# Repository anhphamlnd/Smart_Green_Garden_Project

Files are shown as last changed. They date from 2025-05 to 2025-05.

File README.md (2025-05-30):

# Smart_Garden_Project
# 🌱 Smart Garden v2.1 (AVR)
## ĐẶT VẤN ĐỀ
### Khái quát
Trong thời đại công nghệ, việc ứng dụng các hệ thống thông minh sử dụng cảm
biến đang trở thành xu hướng phổ biến. Các cảm biến được tích hợp giúp thu thập dữ
liệu về nhiệt độ, ánh sáng, chuyển động, và nhiều thông tin khác. Từ đó, vườn rau có
thể tự động điều khiển, mang lại sự tiện nghi, an toàn và tiết kiệm năng lượng.
### Lý do chọn đề tài
Việc thiết kế hệ thống vườn thông minh sử dụng các cảm biến là một đề tài có
nhiều tiềm năng ứng dụng trong thực tế. Các lý do chính khiến đề tài này được lựa
chọn bao gồm: Nhu cầu ngày càng tăng về sự tiện lợi, an toàn và tiết kiệm năng lượng
trong quá trình sản xuất; Tiềm năng thị trường lớn cho các giải pháp nông nghiệp
thông minh sử dụng cảm biến có giá thành hợp lý và dễ ứng dụng; Phù hợp với thời
gian nghiên cứu và mục tiêu môn học đề ra.

### 👨‍💻 MCU: ATmega328P  
### 🧠 IDE: CodeVisionAVR  
### 📅 Dự án cuối kỳ — Hệ thống vườn thông minh bán tự động

---

## 📌 Tính năng chính

- 👏 **Điều khiển LED bằng 2 tiếng vỗ tay (KY-037)**
- 🚪 **Mở cổng servo khi phát hiện vật cản (FC-51)**
- 🌡️ **Đo và hiển thị nhiệt độ/độ ẩm bằng DHT11**
- 📟 **Hiển thị thông tin trên màn hình OLED SSD1306**
- 🚨 **Cảnh báo nhiệt độ cao bằng buzzer**
- ⏱️ **Hiển thị thời gian hoạt động hệ thống (uptime)**

---

## ⚙️ Phần cứng sử dụng

| Thiết bị | Mô tả |
|---|---|
| ATmega328P | Vi điều khiển chính |
| DHT11 | Cảm biến nhiệt độ và độ ẩm |
| KY-037 | Cảm biến âm thanh (vỗ tay) |
| FC-51 | Cảm biến vật cản hồng ngoại |
| Servo SG90 | Đóng/mở cổng thông minh |
| OLED SSD1306 (I2C) | Hiển thị dữ liệu |
| Buzzer | Cảnh báo nhiệt độ cao |
| LED | Phản hồi khi vỗ tay |

---

## 🧠 Mô tả chi tiết hoạt động

### 1. 👏 **Vỗ tay bật/tắt đèn**
- Khi phát hiện **2 tiếng vỗ tay liên tiếp**, hệ thống bật/tắt LED.
- Debounce chống nhiễu âm thanh được tích hợp.

### 2. 🚪 **Cảm biến vật cản mở cổng**
- FC-51 phát hiện người/động vật → điều khiển servo mở cửa trong 5 giây → tự đóng.

### 3. 🌡️ **Đo nhiệt độ và cảnh báo**
- Dữ liệu nhiệt độ/độ ẩm được đo mỗi 2 giây.
- Nếu nhiệt độ vượt ngưỡng (mặc định >38°C), buzzer phát cảnh báo chớp nháy.

### 4. 📟 **OLED hiển thị**
- Thông tin được cập nhật:
  - Nhiệt độ
  - Độ ẩm
  - Trạng thái cảnh báo
  - Uptime tính theo `giờ:phút:giây`

---

## 🧾 Sơ đồ kết nối (Pinout)

| Thiết bị | ATmega328P Pin |
|---|---|
| KY-037 | PD4 (Digital)  |
| FC-51 | PD5 (Digital)  |
| DHT11 | PD6 (Digital)  |
| Servo | PD3 (OC2B PWM) |
| OLED (SCL) | PC5 (A5) |
| OLED (SDA) | PC4 (A4) |
| Buzzer | PB0 (Digital)  |
| LED | PB1 (Digital)  |

---
## Chi tiết hoạt động của dự án
### Khi bắt đầu chương trình 
https://github.com/user-attachments/assets/0a29f42b-ba93-440f-8400-c172d5bd55a2

### Khối mở cửa
https://github.com/user-attachments/assets/b30ab63e-868c-456a-b049-d4f57b4c9ab6

### Khối bật tắt đèn khi clap 2 lần 
https://github.com/user-attachments/assets/f04b529f-8dd0-40fd-a486-890ce29304f3

### Cảnh báo khi nhiệt độ > 38 độ C
https://github.com/user-attachments/assets/04ab473f-949c-4921-8430-c594595824e2

## 💻 Cấu trúc chương trình

```c
- main()
  ├── init_all()
  ├── while(1)
       ├── check_clap_switch()
       ├── check_obstacle_sensor()
       ├── check_dht_and_update_display()
       └── update_uptime_display()

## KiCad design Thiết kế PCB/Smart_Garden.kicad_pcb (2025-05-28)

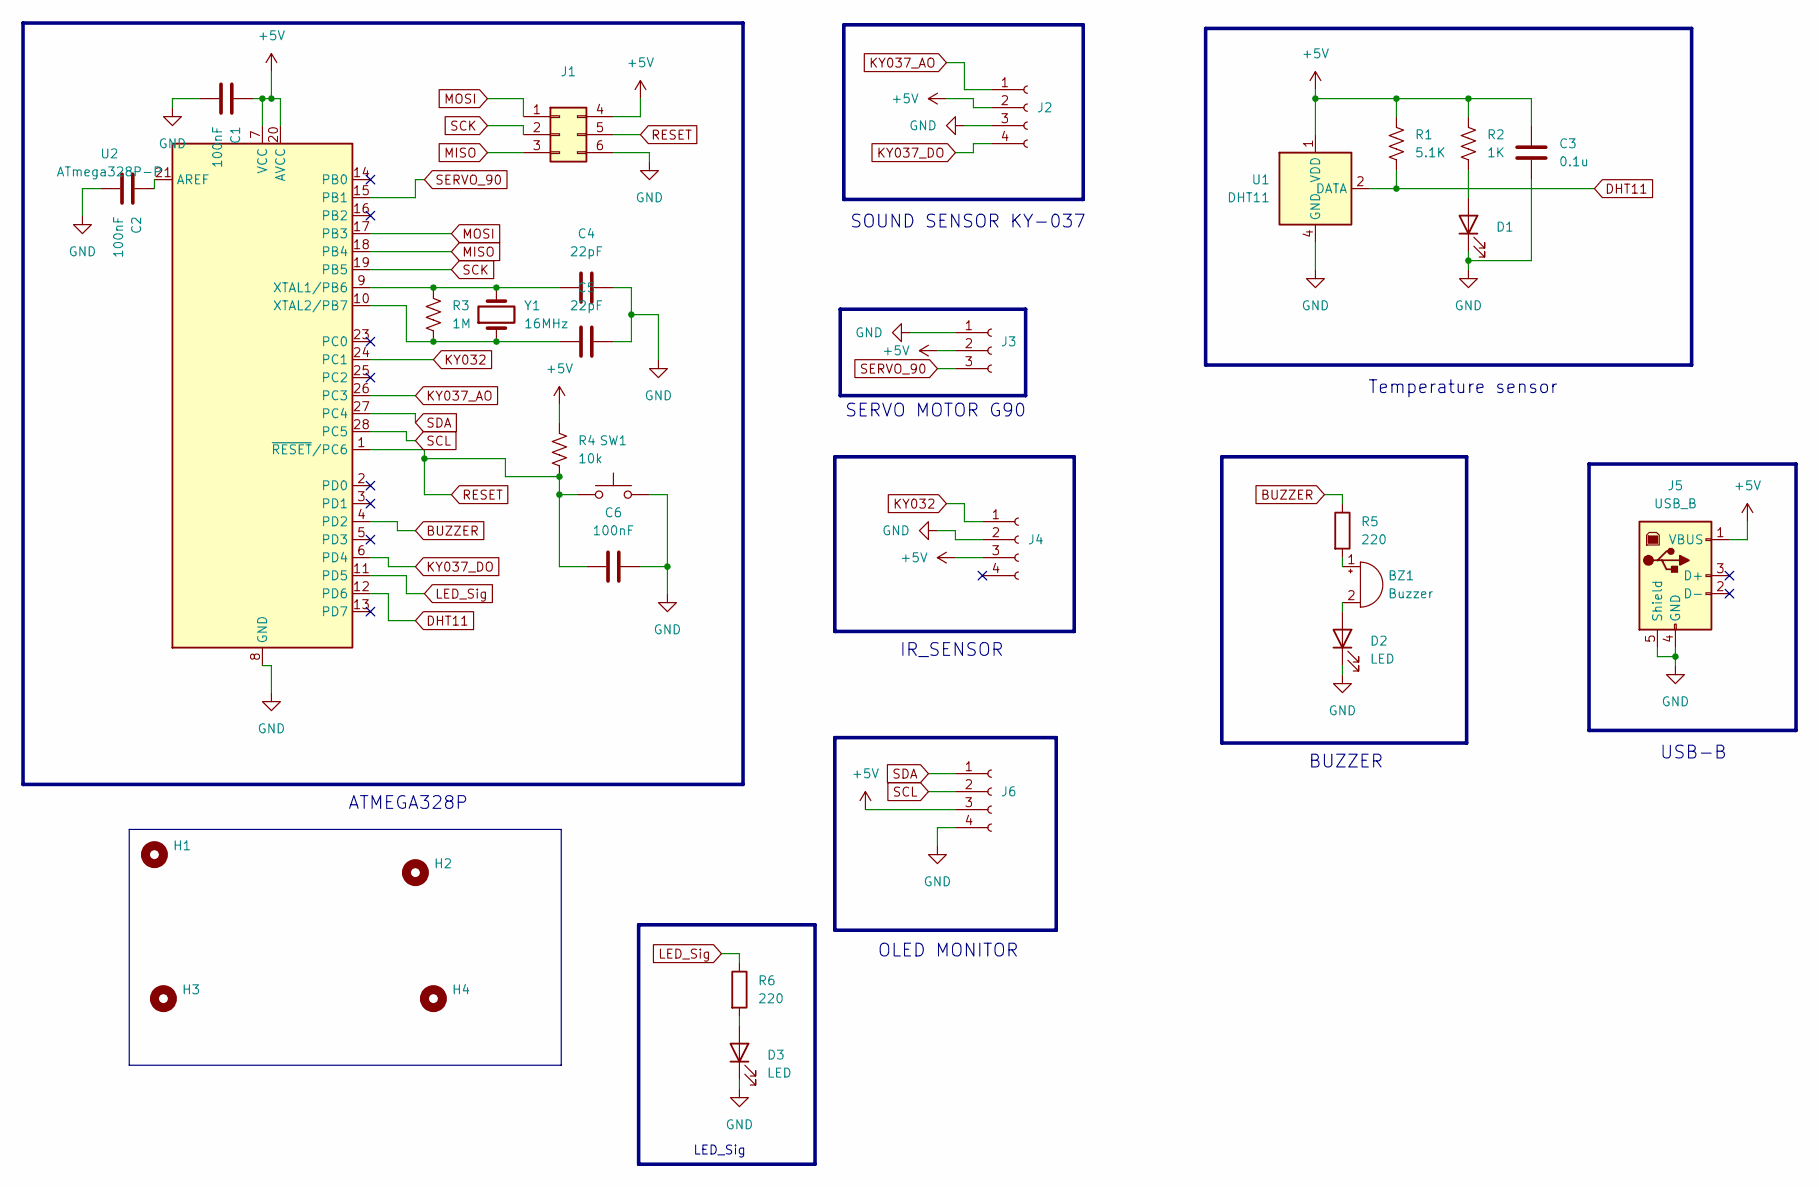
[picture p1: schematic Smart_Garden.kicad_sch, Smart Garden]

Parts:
BZ1: Buzzer; Buzzer_12x9.5RM7.6
C1, C2, C6: 100nF; CP_Radial_D4.0mm_P1.50mm
C3: 0.1u; CP_Radial_D4.0mm_P1.50mm
C4, C5: 22pF; CP_Radial_D4.0mm_P1.50mm
D1, D2, D3: LED; LED_D4.0mm
H1, H2, H3, H4: MountingHole; MountingHole_3.2mm_M3_DIN965
J1: Conn_02x03_Top_Bottom; PinSocket_2x03_P2.54mm_Vertical
J2, J4, J6: Conn_01x04_Socket; PinSocket_1x04_P2.54mm_Vertical
J3: Conn_01x03_Socket; PinSocket_1x03_P2.54mm_Vertical
J5: USB_B; USB_B_Lumberg_2411_02_Horizontal
R1: 5.1K; R_Axial_DIN0309_L9.0mm_D3.2mm_P12.70mm_Horizontal
R2: 1K; R_Axial_DIN0309_L9.0mm_D3.2mm_P12.70mm_Horizontal
R3: 1M; R_Axial_DIN0309_L9.0mm_D3.2mm_P12.70mm_Horizontal
R4: 10k; R_Axial_DIN0309_L9.0mm_D3.2mm_P12.70mm_Horizontal
R5, R6: 220; R_Axial_DIN0309_L9.0mm_D3.2mm_P12.70mm_Horizontal
SW1: SW_Push; SW_PUSH-12mm
U1: DHT11; Aosong_DHT11_5.5x12.0_P2.54mm
U2: ATmega328P-P; DIP-28_W7.62mm_Socket
Y1: 16MHz; Crystal_HC49-U_Vertical

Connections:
+5V: C1.2, C3.1, J1.4, J2.2, J3.2, J4.3, J5.1 (VBUS), J6.3, R1.1, R2.1, R4.2, U1.1 (VDD), U2.7 (VCC), U2.20 (AVCC)
BUZZER: R5.1, U2.4 (PD2)
DHT11: R1.2, U1.2 (DATA), U2.12 (PD6)
GND: C1.1, C2.1, C3.2, C4.2, C5.2, C6.2, D1.1 (K), D2.1 (K), D3.1 (K), J1.6, J2.3, J3.1, J4.2, J5.4 (GND), J5.5 (Shield), J6.4, SW1.2, U1.4 (GND), U2.8 (GND), U2.22 (GND)
KY032: J4.1, U2.24 (PC1)
KY037_AO: J2.1, U2.26 (PC3)
KY037_DO: J2.4, U2.6 (PD4)
LED_Sig: R6.1, U2.11 (PD5)
MISO: J1.3, U2.18 (PB4)
MOSI: J1.1, U2.17 (PB3)
unnamed: BZ1.1 (+), R5.2
unnamed: BZ1.2 (-), D2.2 (A)
unnamed: D1.2 (A), R2.2
unnamed: D3.2 (A), R6.2
unnamed: C2.2, U2.21 (AREF)
unnamed: C4.1, R3.1, U2.9 (XTAL1/PB6), Y1.2
unnamed: C5.1, R3.2, U2.10 (XTAL2/PB7), Y1.1
RESET: C6.1, J1.5, R4.1, SW1.1, U2.1 (~RESET/PC6)
SCK: J1.2, U2.19 (PB5)
SCL: J6.2, U2.28 (PC5)
SDA: J6.1, U2.27 (PC4)
SERVO_90: J3.3, U2.15 (PB1)

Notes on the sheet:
ATMEGA328P
OLED MONITOR
BUZZER
Temperature sensor
LED_Sig
IR_SENSOR
SOUND SENSOR KY-037
USB-B
SERVO MOTOR G90

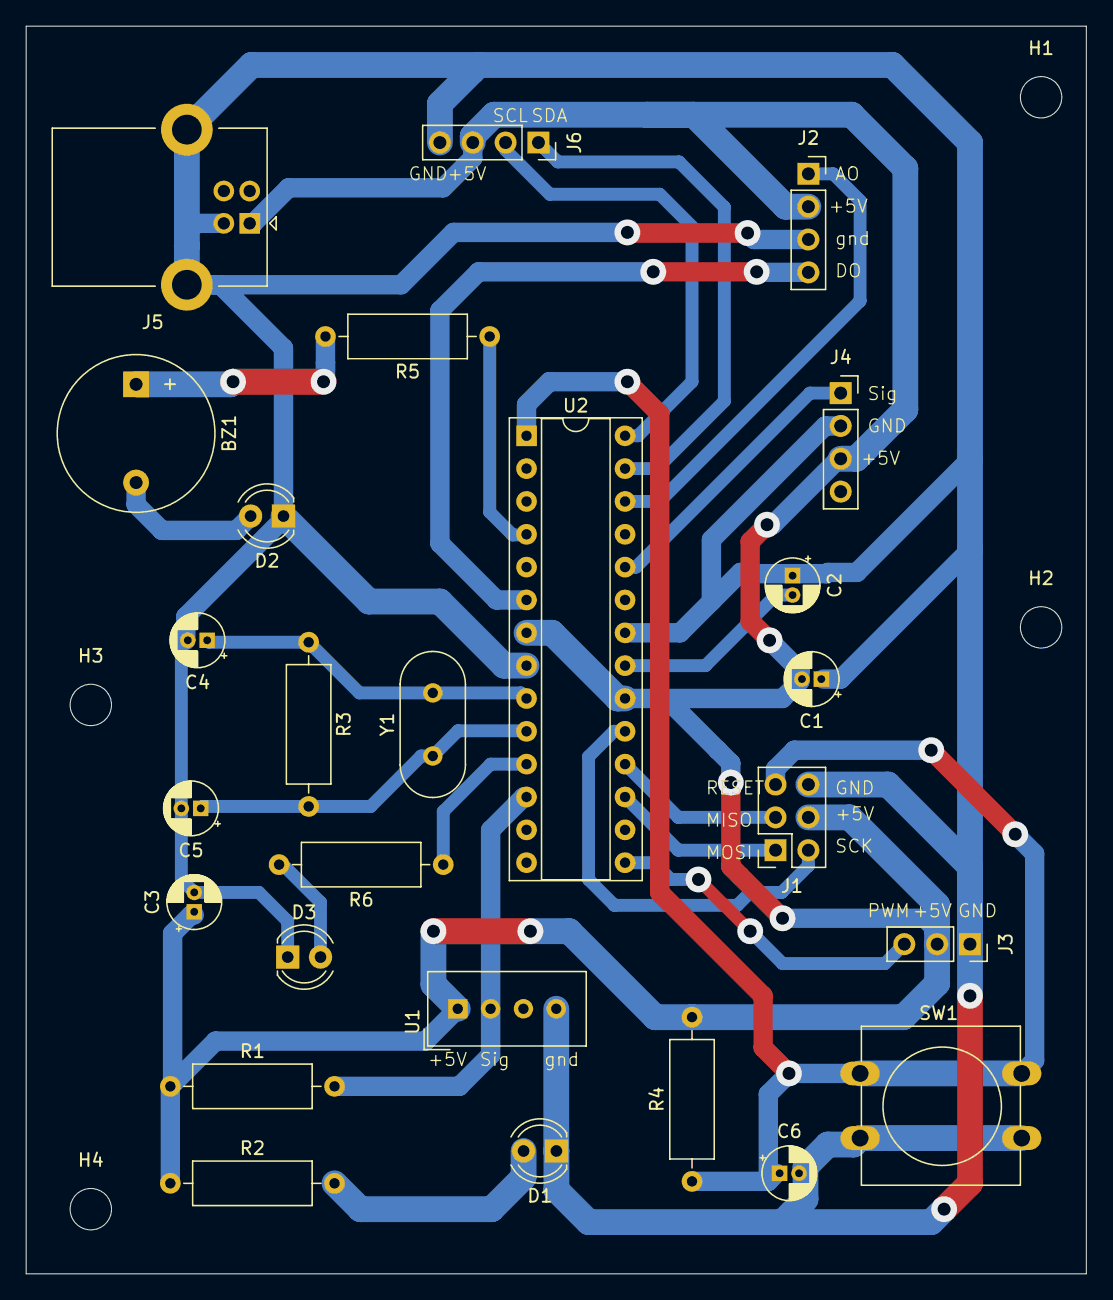
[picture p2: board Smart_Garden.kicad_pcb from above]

Board: 2 copper layers, 82.0 x 96.5 mm, 30 parts (0 on the bottom side), 22 nets.

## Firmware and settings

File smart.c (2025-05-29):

#include <mega328p.h>
#include <delay.h>
#include "oled_display.h"
#include <stdint.h>
#include <stdio.h>

// === PIN DEFINITIONS ===
// Smart Gate pins
#define DHT_PIN PIND6
#define FC51_PIN PINC1
#define BUZZER_PIN PIND2
#define SERVO_PIN PINB1

// Clap Switch pins
#define LED_PIN PIND5
#define SOUND_SENSOR_PIN PINC3

// === GLOBAL VARIABLES ===
// Timer & Millis 
volatile unsigned long millis_counter = 0;
volatile unsigned char timer_overflow_count = 0;

// DHT11 variables
unsigned int I_RH, D_RH, I_Temp, D_Temp, CheckSum;
char display_buffer[20];
unsigned char dht_error = 0;

// Gate control variables
unsigned char hasObstacle = 0, past_obstacle = 0;

// Clap switch variables 
unsigned char led_state = 0;
unsigned char sound_detected = 0;
unsigned char last_sound_state = 1; // KY-037 idle = HIGH
unsigned long clap_timer = 0;
unsigned char clap_count = 0;
unsigned char waiting_for_second_clap = 0;

// System timing
unsigned long last_dht_read = 0;
unsigned long last_display_update = 0;

// Debug variables 
unsigned int debug_seconds = 0;
unsigned long debug_last_second = 0;

// Temperature alert variables
unsigned char temp_alert_active = 0;
unsigned long temp_alert_start_time = 0;
unsigned long temp_alert_last_toggle = 0;
unsigned char temp_alert_buzzer_state = 0;

// === TIMER & MILLIS FUNCTIONS ===
void timer0_init() {
    // Clear timer registers
    TCCR0A = 0x00;
    TCCR0B = 0x00;
    TCNT0 = 0x00;
    
    // Configure for CTC mode with proper prescaler
    TCCR0A = (1 << WGM01);  // CTC mode
    TCCR0B = (1 << CS01) | (1 << CS00);  // Prescaler 64
    
    // Set compare value for 1ms interrupt at 16MHz
    // (16MHz / 64) / 1000Hz = 250
    OCR0A = 249;  // 250 - 1
    
    // Enable compare match interrupt
    TIMSK0 = (1 << OCIE0A);
    
    // Enable global interrupts
    #asm("sei");
}

// Interrupt handler
interrupt [TIM0_COMPA] void timer0_compa_isr(void) {
    millis_counter++;
    timer_overflow_count++;
    
    // Reset overflow counter every second for debug
    if (timer_overflow_count >= 1000) {  // 250 * 4ms = 1000ms
        timer_overflow_count = 0;
    }
}

unsigned long millis() {
    unsigned long temp;
    #asm("cli");
    temp = millis_counter;
    #asm("sei");
    return temp;
}

// Function to get seconds with proper handling
unsigned int get_uptime_seconds() {
    unsigned long current_millis = millis();
    return (unsigned int)(current_millis / 1000UL);
}

// Function to format uptime in human readable format
void format_uptime(char* buffer, unsigned long total_seconds) {
    unsigned int days, hours, minutes, seconds;
    
    days = total_seconds / 86400UL;     // 86400 seconds in a day
    total_seconds %= 86400UL;
    
    hours = total_seconds / 3600UL;     // 3600 seconds in an hour
    total_seconds %= 3600UL;
    
    minutes = total_seconds / 60UL;     // 60 seconds in a minute
    seconds = total_seconds % 60UL;
    
    // Format based on time duration
    if (days > 0) {
        if (hours > 0) {
            sprintf(buffer, "%ud%uh%um%us", days, hours, minutes, seconds);
        } else if (minutes > 0) {
            sprintf(buffer, "%ud%um%us", days, minutes, seconds);
        } else {
            sprintf(buffer, "%ud%us", days, seconds);
        }
    } else if (hours > 0) {
        if (minutes > 0) {
            sprintf(buffer, "%uh%um%us", hours, minutes, seconds);
        } else {
            sprintf(buffer, "%uh%us", hours, seconds);
        }
    } else if (minutes > 0) {
        sprintf(buffer, "%um%us", minutes, seconds);
    } else {
        sprintf(buffer, "%us", seconds);
    }
}

// === SERVO CONTROL FUNCTIONS ===
void servo_setup() {
    DDRB |= (1 << 1); // PB1 output (SERVO_PIN)
    
    // Timer1 setup
    TCCR1A = 0x00;
    TCCR1B = 0x00;
    TCCR1A |= (1 << WGM11);
    TCCR1B |= (1 << WGM12) | (1 << WGM13);
    TCCR1A |= (1 << COM1A1);
    TCCR1B |= (1 << CS11); // Prescaler 8
    
    // Set ICR1 = 40000 for 20ms period (exactly like your code)
    ICR1H = 0b10011100;  // 0x9C
    ICR1L = 0b01000000;  // 0x40
    
    // Initial position (closed) - using your exact values
    OCR1AH = 0b00000100;  // 0x04
    OCR1AL = 0b00100100;  // 0x24
}

void open_gate() {
    OCR1AH = 0b00001011;  // 0x0B
    OCR1AL = 0b01111100;  // 0x7C
}

void close_gate() {
    OCR1AH = 0b00000100;  // 0x04
    OCR1AL = 0b00100100;  // 0x24
}

// === DHT11 FUNCTIONS ===
void dht_request() {
    DDRD |= (1 << DHT_PIN);
    PORTD &= ~(1 << DHT_PIN);
    delay_ms(20);
    PORTD |= (1 << DHT_PIN);
    delay_us(30);
}

void dht_response() {
    DDRD &= ~(1 << DHT_PIN);
    while (PIND & (1 << DHT_PIN));
    while (!(PIND & (1 << DHT_PIN)));
    while (PIND & (1 << DHT_PIN));
}

uint8_t dht_receive_data() {
    uint8_t c = 0;
    int q;
    for (q = 0; q < 8; q++) {
        while (!(PIND & (1 << DHT_PIN)));
        delay_us(30);
        if (PIND & (1 << DHT_PIN))
            c = (c << 1) | 1;
        else
            c = (c << 1);
        while (PIND & (1 << DHT_PIN));
    }
    return c;
}

unsigned char read_dht11() {
    dht_request();
    dht_response();
    
    I_RH = dht_receive_data();
    D_RH = dht_receive_data();
    I_Temp = dht_receive_data();
    D_Temp = dht_receive_data();
    CheckSum = dht_receive_data();
    
    // Verify checksum
    if ((I_RH + D_RH + I_Temp + D_Temp) == CheckSum) {
        dht_error = 0;
        return 1; // Success
    } else {
        dht_error = 1;
        return 0; // Error
    }
}

// === TEMPERATURE ALERT FUNCTIONS ===
void check_temperature_alert() {
    unsigned long current_time = millis();
    
    // Check if temperature is above 38°C and no error
    if (!dht_error && I_Temp >= 38) {
        if (!temp_alert_active) {
            // Start temperature alert
            temp_alert_active = 1;
            temp_alert_start_time = current_time;
            temp_alert_last_toggle = current_time;
            temp_alert_buzzer_state = 0;
        }
    } else {
        // Temperature is normal or DHT error - stop alert
        temp_alert_active = 0;
        if (temp_alert_buzzer_state) {
            PORTD &= ~(1 << BUZZER_PIN);  // Turn off buzzer
            temp_alert_buzzer_state = 0;
        }
    }
    
    // Handle temperature alert blinking
    if (temp_alert_active) {
        // Check if 5 seconds have passed
        if (current_time - temp_alert_start_time >= 5000) {
            // 5 seconds completed - stop alert
            temp_alert_active = 0;
            if (temp_alert_buzzer_state) {
                PORTD &= ~(1 << BUZZER_PIN);
                temp_alert_buzzer_state = 0;
            }
        } else {
            // Blink buzzer every 200ms (5Hz frequency)
            if (current_time - temp_alert_last_toggle >= 200) {
                temp_alert_buzzer_state = !temp_alert_buzzer_state;
                temp_alert_last_toggle = current_time;
                
                if (temp_alert_buzzer_state) {
                    PORTD |= (1 << BUZZER_PIN);   // Buzzer on
                } else {
                    PORTD &= ~(1 << BUZZER_PIN);  // Buzzer off
                }
            }
        }
    }
}

// === CLAP SWITCH FUNCTIONS ===
void set_led(unsigned char state) {
    led_state = state;
    if (led_state) {
        PORTD |= (1 << LED_PIN);
    } else {
        PORTD &= ~(1 << LED_PIN);
    }
}

void handle_clap_switch() {
    unsigned long current_time;
    unsigned char current_sound;
    
    current_time = millis();
    current_sound = (PINC & (1 << SOUND_SENSOR_PIN)) ? 1 : 0;
    
    // Detect falling edge (HIGH -> LOW) = sound detected
    if (last_sound_state == 1 && current_sound == 0) {
        if (!waiting_for_second_clap) {
            // First clap
            waiting_for_second_clap = 1;
            clap_timer = current_time;
            clap_count = 1;
        } else if (current_time - clap_timer > 30 && current_time - clap_timer < 200) {
            // Second clap (within 30ms - 200ms) - very fast
            clap_count = 2;
            // Toggle LED immediately
            set_led(!led_state);
            // Reset state
            waiting_for_second_clap = 0;
            clap_count = 0;
            clap_timer = 0;
        }
    }
    
    // Timeout - reset if no second clap within 200ms
    if (waiting_for_second_clap && (current_time - clap_timer > 200)) {
        waiting_for_second_clap = 0;
        clap_count = 0;
        clap_timer = 0;
    }
    
    last_sound_state = current_sound;
}

// === DISPLAY FUNCTIONS ===
void update_display() {
    // Declare all variables at the beginning
    unsigned long current_millis;
    unsigned long uptime_seconds_long;
    unsigned int uptime_seconds;
    unsigned int deciseconds;
    unsigned int raw_counter;
    char uptime_formatted[16];
    
    ssd1306_clear();
    
    // Title
    ssd1306_set_cursor(0, 0);
    ssd1306_print("Smart Garden v2.1");
    
    // DHT11 data with temperature alert indicator
    if (!dht_error) {
        ssd1306_set_cursor(0, 2);
        if (temp_alert_active && I_Temp >= 38) {
            sprintf(display_buffer, "Temp : %d.%d C !HOT!", I_Temp, D_Temp);
        } else {
            sprintf(display_buffer, "Temp : %d.%d C", I_Temp, D_Temp);
        }
        ssd1306_print(display_buffer);
        
        ssd1306_set_cursor(0, 3);
        sprintf(display_buffer, "Hum  : %d.%d %%", I_RH, D_RH);
        ssd1306_print(display_buffer);
    } else {
        ssd1306_set_cursor(0, 2);
        ssd1306_print("DHT11: Error");
    }
    
    // Gate status
    ssd1306_set_cursor(0, 5);
    if (hasObstacle) {
        ssd1306_print("Gate: OPEN");
    } else {
        ssd1306_print("Gate: CLOSE");
    }
    
    // LED status
    ssd1306_set_cursor(0, 6);
    if (led_state) {
        ssd1306_print("LED: ON");
    } else {
        ssd1306_print("LED: OFF");
    }
    
    // Temperature alert status
    ssd1306_set_cursor(68, 5);
    if (temp_alert_active) {
        unsigned long remaining = 5000 - (millis() - temp_alert_start_time);
        sprintf(display_buffer, "ALERT:%us", (unsigned int)(remaining/1000 + 1));
        ssd1306_print(display_buffer);
    }
    
    // Clap debug info (can be removed after testing)
    ssd1306_set_cursor(64, 6);
    if (waiting_for_second_clap) {
        ssd1306_print("Wait2nd");
    } else {
        sprintf(display_buffer, "C:%d", clap_count);
        ssd1306_print(display_buffer);
    }
    
    // System uptime - ENHANCED with human readable format
    ssd1306_set_cursor(0, 7);
    
    // Get current values
    current_millis = millis();
    uptime_seconds = get_uptime_seconds();
    
    if (current_millis > 0 && uptime_seconds > 0) {
        // Format uptime in human readable format
        uptime_seconds_long = (unsigned long)uptime_seconds;
        format_uptime(uptime_formatted, uptime_seconds_long);
        sprintf(display_buffer, "Up:%s", uptime_formatted);
        ssd1306_print(display_buffer);
    } else if (current_millis > 0) {
        // Fallback 1: Show milliseconds/100
        deciseconds = (unsigned int)(current_millis / 100UL);
        sprintf(display_buffer, "Up: %u.%us", deciseconds/10, deciseconds%10);
        ssd1306_print(display_buffer);
    } else {
        // Fallback 2: Show raw counter
        #asm("cli");
        raw_counter = (unsigned int)(millis_counter & 0xFFFF);
        #asm("sei");
        sprintf(display_buffer, "Cnt: %u", raw_counter);
        ssd1306_print(display_buffer);
    }
    
    ssd1306_display();
}

// Debug function to test timer
void debug_timer() {
    unsigned long current_time;
    static unsigned char debug_led = 0;
    
    current_time = millis();
    
    // Update debug seconds counter
    if (current_time - debug_last_second >= 1000) {
        debug_seconds++;
        debug_last_second = current_time;
        
        // Blink built-in LED every second for visual confirmation
        debug_led = !debug_led;
        if (debug_led) {
            PORTB |= (1 << 5);  // Arduino pin 13
        } else {
            PORTB &= ~(1 << 5);
        }
    }
}

// === SYSTEM INITIALIZATION ===
void system_init() {
    int i;
    
    // Configure debug LED (pin 13)
    DDRB |= (1 << 5);
    PORTB &= ~(1 << 5);
    
    // Initialize OLED
    SSD1306_Init();
    ssd1306_clear();
    
    // Show startup message
    ssd1306_set_cursor(0, 2);
    ssd1306_print("Initializing...");
    ssd1306_set_cursor(0, 4);
    ssd1306_print("Anh va Hoi design");
    ssd1306_display();
    delay_ms(2000);
    
    // Initialize timer FIRST - IMPORTANT
    timer0_init();
    
    // Initialize servo
    servo_setup();
    close_gate();
    
    // Configure pins
    // Gate control pins
    DDRC &= ~(1 << FC51_PIN);    // FC51 input
    PORTC |= (1 << FC51_PIN);    // Pull-up
    DDRD |= (1 << BUZZER_PIN);   // Buzzer output
    PORTD &= ~(1 << BUZZER_PIN); // Buzzer off
    
    // Clap switch pins
    DDRD |= (1 << LED_PIN);      // LED output
    PORTD &= ~(1 << LED_PIN);    // LED off
    DDRC &= ~(1 << SOUND_SENSOR_PIN); // Sound sensor input
    PORTC |= (1 << SOUND_SENSOR_PIN); // Pull-up
    
    // Startup LED sequence
    for (i = 0; i < 3; i++) {
        PORTD |= (1 << LED_PIN);
        delay_ms(200);
        PORTD &= ~(1 << LED_PIN);
        delay_ms(200);
    }
    
    // Initialize variables
    led_state = 0;
    sound_detected = 0;
    last_sound_state = 1;
    clap_timer = 0;
    clap_count = 0;
    waiting_for_second_clap = 0;
    hasObstacle = 0;
    past_obstacle = 0;
    last_dht_read = 0;
    last_display_update = 0;
    debug_seconds = 0;
    debug_last_second = 0;
    
    // Initialize temperature alert variables
    temp_alert_active = 0;
    temp_alert_start_time = 0;
    temp_alert_last_toggle = 0;
    temp_alert_buzzer_state = 0;
    
    // Wait for timer to start
    delay_ms(100);
    
    ssd1306_clear();
    ssd1306_set_cursor(0, 3);
    ssd1306_print("System Ready!");
    
    // Show timer status
    ssd1306_set_cursor(0, 5);
    if (millis() > 0) {
        ssd1306_print("Timer: OK");
    } else {
        ssd1306_print("Timer: ERROR");
    }
    
    ssd1306_display();
    delay_ms(1000);
}

// === MAIN FUNCTION ===
void main(void) {
    unsigned long current_time;
    
    // System initialization
    system_init();
    
    while (1) {
        current_time = millis();
        
        // Debug timer function
        debug_timer();
        
        // Read DHT11 every 2 seconds
        if (current_time - last_dht_read >= 2000) {
            read_dht11();
            last_dht_read = current_time;
        }
        
        // Check temperature alert - NEW
        check_temperature_alert();
        
        // Check obstacle sensor
        hasObstacle = !(PINC & (1 << FC51_PIN));
        
        if (hasObstacle) {
            // Object detected - open gate
            if (past_obstacle != hasObstacle) {
                open_gate();
                // Only sound obstacle buzzer if not in temperature alert mode
                if (!temp_alert_active) {
                    PORTD |= (1 << BUZZER_PIN);   // Buzzer on
                    delay_ms(200);
                    PORTD &= ~(1 << BUZZER_PIN);  // Buzzer off
                }
                delay_ms(1000);
            }
        } else {
            // No object - close gate
            close_gate();
        }
        past_obstacle = hasObstacle;
        
        // Process clap switch - CALL ONLY 1 FUNCTION
        handle_clap_switch();
        
        // Update display every 500ms
        if (current_time - last_display_update >= 500) {
            update_display();
            last_display_update = current_time;
        }
        
    }
}

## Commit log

2025-05-27 Update PCB and simulation
    [Smart_home.kicad_pcb, Smart_home.kicad_sch]
2025-05-27 update algorithm flowchart
2025-05-28 fix comment in code
    [smart.c]
2025-05-28 update name
    [Smart_Garden.kicad_pcb, Smart_Garden.kicad_sch]
2025-05-29 fix timer
    [smart.cfg]
